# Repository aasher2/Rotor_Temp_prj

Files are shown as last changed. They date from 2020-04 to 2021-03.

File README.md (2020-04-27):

# Welcome!

We created this repository in case another team is tasked to bring this project to completion. All necessary documents and many useful links are provided.

To download this entire project as a zipped folder, simply click the "Clone or Download" drop-down to the right of the home page. The option to download as a zipped folder will then be presented. 

This repository is split between paths for firmware and hardware. The firmware path just leads to the final code used for the BLE server and BLE client. The hardware path diverges into paths for the final design and for the proof of concept design. Most of the documents/datasheets/references will be found in the proof of concept folder.

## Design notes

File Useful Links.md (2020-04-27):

# Useful Links

## Final Design Digi-key Cart
https://www.digikey.com/short/zz4mqt

## TinyPICO Information
TinyPICO GitHub repository: https://github.com/TinyPICO

## Amazon Links
TinyPICO Development Board: https://www.amazon.com/Unexpected-Maker-TinyPICO/dp/B07ZZKZDGQ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

ESP-WROOM-32 Development Board:
https://www.amazon.com/HiLetgo-ESP-WROOM-32-Development-Microcontroller-Integrated/dp/B0718T232Z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

Adafruit AD8495 Breakout Board:
https://www.amazon.com/Adafruit-Analog-Output-Thermocouple-Amplifier/dp/B00XW2N6E0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

## Calibrating the AD8495
https://www.instructables.com/id/AD8495-Breakout-Board-Solution/

## Setting up ESP32 with Energia/Arduino IDE (same process)
https://randomnerdtutorials.com/installing-the-esp32-board-in-arduino-ide-windows-instructions/

## Setting up BLE with ESP32
https://randomnerdtutorials.com/esp32-bluetooth-low-energy-ble-arduino-ide/

https://www.instructables.com/id/How-to-Use-BluetoothBLE-With-ESP32/

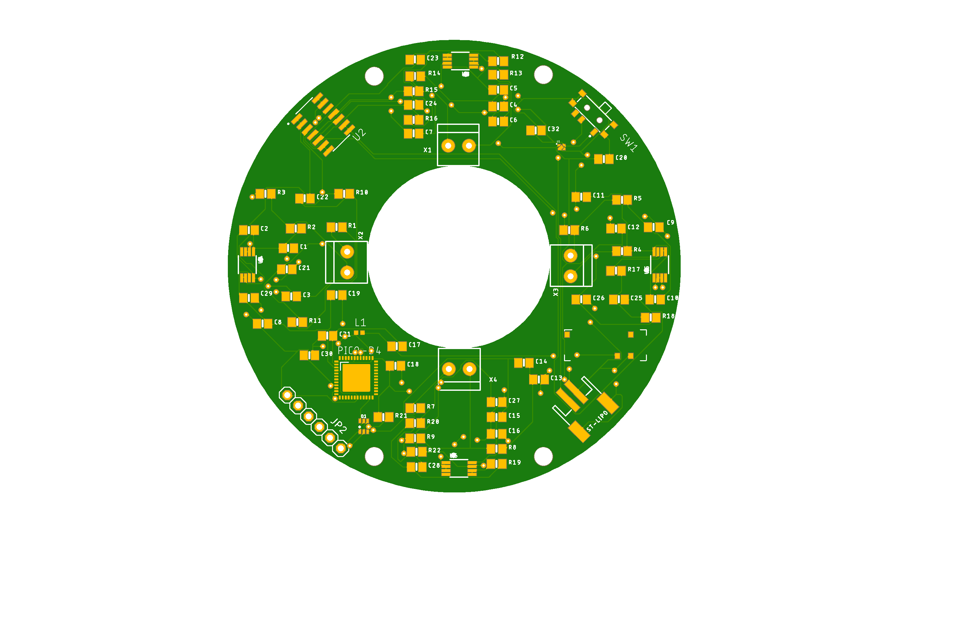
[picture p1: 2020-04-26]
Hardware/Final_Design/Layout.png

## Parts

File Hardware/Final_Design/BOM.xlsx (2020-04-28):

Manufacturer Part Number | Manufacturer | Digi-Key Part Number | Packaging | Quantity | Unit Price | Extended Price | Description | Hyperlink
ESP32-PICO-D4 | Espressif Systems | 1904-1029-1-ND | Cut Tape (CT) | 1 | 4.5 | $4.50 | RX TXRX MOD WIFI SURFACE MOUNT | Link (https://www.digikey.com/product-detail/en/ESP32-PICO-D4/1904-1029-1-ND/9381738/?itemSeq=324698362)
AD8497ARMZ-R7 | Analog Devices Inc. | AD8497ARMZ-R7CT-ND | Cut Tape (CT) | 4 | 6.14 | $24.56 | IC THERMOCOUPLE A W/COMP 8MSOP | Link (https://www.digikey.com/product-detail/en/AD8497ARMZ-R7/AD8497ARMZ-R7CT-ND/4909088/?itemSeq=324698358)
LM324AMX/NOPB | Texas Instruments | LM324AMX/NOPBCT-ND | Cut Tape (CT) | 1 | 1.02 | $1.02 | IC OPAMP GP 4 CIRCUIT 14SOIC | Link (https://www.digikey.com/product-detail/en/LM324AMX%2fNOPB/LM324AMX%2fNOPBCT-ND/1010531/?itemSeq=324698361)
C2012X7T2E104K125AE | TDK Corporation | 445-8883-1-ND | Cut Tape (CT) | 15 | 0.239 | $3.58 | CAP CER 0.1UF 250V X7T 0805 | Link (https://www.digikey.com/product-detail/en/C2012X7T2E104K125AE/445-8883-1-ND/3283672/?itemSeq=324698355)
C0805C103K1RACTU | KEMET | 399-1159-1-ND | Cut Tape (CT) | 5 | 0.1 | $0.50 | CAP CER 10000PF 100V X7R 0805 | Link (https://www.digikey.com/product-detail/en/C0805C103K1RACTU/399-1159-1-ND/411434/?itemSeq=324698359)
RL1220S-101-F | Susumu | 408-1403-1-ND | Cut Tape (CT) | 10 | 0.318 | $3.18 | RES SMD 100 OHM 1% 1/3W 0805 | Link (https://www.digikey.com/product-detail/en/RL1220S-101-F/408-1403-1-ND/2734781/?itemSeq=324698349)
MCU08050D1004BP100 | Vishay Beyschlag | 749-1876-1-ND | Cut Tape (CT) | 5 | 0.58 | $2.90 | RES SMD 1M OHM 0.1% 1/8W 0805 | Link (https://www.digikey.com/product-detail/en/MCU08050D1004BP100/749-1876-1-ND/8555710/?itemSeq=324698341)
ED555/2DS | On Shore Technology Inc. | ED1514-ND | Box | 4 | 1.06 | $4.24 | TERM BLK 2POS SIDE ENT 3.5MM PCB | Link (https://www.digikey.com/product-detail/en/ED555%2f2DS/ED1514-ND/182983/?itemSeq=324698333)
C0805C106J8RACAUTO | KEMET | 399-15693-1-ND | Cut Tape (CT) | 1 | 0.83 | $0.83 | CAP CER 10UF 10V X7R 0805 | Link (https://www.digikey.com/product-detail/en/C0805C106J8RACAUTO/399-15693-1-ND/7427573/?itemSeq=324698344)
CC0805BRNPO9BNR75 | Yageo | 311-4135-1-ND | Cut Tape (CT) | 1 | 0.3 | $0.30 | CAP CER 0.75PF 50V NPO 0805 | Link (https://www.digikey.com/product-detail/en/CC0805BRNPO9BNR75/311-4135-1-ND/8025224/?itemSeq=324698337)
CC0805BRNPO9BN1R5 | Yageo | 311-4126-1-ND | Cut Tape (CT) | 1 | 0.19 | $0.19 | CAP CER 1.5PF 50V NPO 0805 | Link (https://www.digikey.com/product-detail/en/CC0805BRNPO9BN1R5/311-4126-1-ND/8025215/?itemSeq=324698346)
C0805C105K4RACTU | KEMET | 399-1284-1-ND | Cut Tape (CT) | 2 | 0.15 | $0.30 | CAP CER 1UF 16V X7R 0805 | Link (https://www.digikey.com/product-detail/en/C0805C105K4RACTU/399-1284-1-ND/416060/?itemSeq=324698338)
0805CS-7N5EKTS | Delta Electronics/Components | 2035-1315-1-ND | Cut Tape (CT) | 2 | 0.25 | $0.50 | CHIP INDUCTOR 7.5NH10% 600MA 0.1 | Link (https://www.digikey.com/product-detail/en/0805CS-7N5EKTS/2035-1315-1-ND/10129548/?itemSeq=324698352)
NCP170AMX300TCG | ON Semiconductor | NCP170AMX300TCGOSCT-ND | Cut Tape (CT) | 1 | 0.47 | $0.47 | IC REG LINEAR 3V 150MA 4XDFN | Link (https://www.digikey.com/product-detail/en/NCP170AMX300TCG/NCP170AMX300TCGOSCT-ND/5131385/?itemSeq=324698343)
1578 | Adafruit Industries LLC | 1528-1841-ND | Bulk | 1 | 7.95 | $7.95 | BATTERY LITHIUM 3.7V 500MAH | Link (https://www.digikey.com/product-detail/en/1578/1528-1841-ND/5054539/?itemSeq=324698327)
PRO-OB-440 | Proant AB | 1532-1001-1-ND | Cut Tape (CT) | 1 | 0.74 | $0.74 | RF ANT 2.4GHZ STAMPED MET SLD | Link (https://www.digikey.com/product-detail/en/PRO-OB-440/1532-1001-1-ND/4895684/?itemSeq=324698329)
RC0805FR-0710KL | Yageo | 311-10.0KCRCT-ND | Cut Tape (CT) | 5 | 0.1 | $0.50 | RES SMD 10K OHM 1% 1/8W 0805 | Link (https://www.digikey.com/product-detail/en/RC0805FR-0710KL/311-10.0KCRCT-ND/730482/?itemSeq=324698381)
S2B-PH-SM4-TB(LF)(SN) | JST Sales America Inc. | 455-1749-1-ND | Cut Tape (CT) | 1 | 0.58 | $0.58 | CONN HEADER SMD R/A 2POS 2MM | Link (https://www.digikey.com/product-detail/en/S2B-PH-SM4-TB(LF)(SN)/455-1749-1-ND/926846/?itemSeq=324698326)
HVC0805T2504JET | Ohmite | HVC0805T2504JETCT-ND | Cut Tape (CT) | 5 | 1.88 | $9.40 | RES SMD 2.5M OHM 5% 1/8W 0805 | Link (https://www.digikey.com/product-detail/en/HVC0805T2504JET/HVC0805T2504JETCT-ND/4809224/?itemSeq=324698328)
CRG0805F150K | TE Connectivity Passive Product | A126340CT-ND | Cut Tape (CT) | 5 | 0.1 | $0.50 | RES SMD 150K OHM 1% 1/8W 0805 | Link (https://www.digikey.com/product-detail/en/CRG0805F150K/A126340CT-ND/7603395/?itemSeq=324698383)
C0805C103K1RAC7210 | KEMET | 399-17617-2-ND | Tape & Reel (TR) | 8 | 0.1 | $0.80 | CAP CER SMD 0805 .01UF 100V X7R | Link (https://www.digikey.com/product-detail/en/C0805C103K1RAC7210/399-17617-1-ND/8572617/?itemSeq=324698382)
RC0805FR-0710KL | Yageo | 311-10.0KCRTR-ND | Tape & Reel (TR) | 2 | 0.1 | $0.20 | RES SMD 10K OHM 1% 1/8W 0805 | Link (https://www.digikey.com/product-detail/en/RC0805FR-0710KL/311-10.0KCRCT-ND/730482/?itemSeq=324698381)
MLL1200S | TE Connectivity ALCOSWITCH Switches | 450-1577-ND | Bulk | 1 | 2.54 | $2.54 | SWITCH SLIDE SPDT 300MA 4V | Link (https://www.digikey.com/product-detail/en/MLL1200S/450-1577-ND/1201378/?itemSeq=324698308)
MBT3904DW1T1G | ON Semiconductor | MBT3904DW1T1GOSTR-ND | Tape & Reel (TR) | 1 | 0.19 | $0.19 | TRANS 2NPN 40V 0.2A SC88 | Link (https://www.digikey.com/product-detail/en/MBT3904DW1T1G/MBT3904DW1T1GOSCT-ND/918012/?itemSeq=324698321)
D01-9923246 | Harwin Inc. | 952-2521-ND | Bulk | 1 | 5.23 | $5.23 | CONN SIL HDR MALE PIN 32POS TIN | Link (https://www.digikey.com/product-detail/en/D01-9923246/952-2521-ND/3918909/?itemSeq=324698310)
3309 | Adafruit Industries LLC | 1528-1800-ND | Bulk | 1 | 5.95 | $5.95 | CP2104 FRIEND USB TO SERIAL BRD | Link (https://www.digikey.com/product-detail/en/3309/1528-1800-ND/6560940/?itemSeq=324698306)
1904 | Adafruit Industries LLC | N/A |  | 1 | 6.95 | $6.95 | Adafruit Micro-Lipo Charger for LiPo/LiIon Batt w/MicroUSB Jack | Link (https://www.adafruit.com/product/1904)

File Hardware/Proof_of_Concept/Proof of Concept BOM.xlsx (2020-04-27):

Test Circuit Component Breakdown
# | Description | Manufacturer/Seller | Vendor | Quanity | Price per Unit | Extended Price
1 | PCB Prototype Board | AiTrip | Amazon | 1 | $10.29 | $10.29
2 | TinyPico Development Board | Unexpected Maker | Amazon | 1 | $29.95 | $29.95
3 | LiPo Battery Charger | Adafruit Industries LLC | Amazon | 1 | $8.30 | $8.30
4 | ESP-WROOM-32 Development Board | HiLetgo | Amazon | 1 | $10.99 | $10.99
5 | 1200 mAh LiPo Battery | Adafruit Industries LLC | Adafruit Industries LLC | 1 | $9.95 | $9.95
6 | AD8495 Breakout Board | Adafruit Industries LLC | Amazon | 1 | $16.98 | $16.98
7 | K-Type Thermocouple | Digilent, Inc. | Digi-Key | 2 | $9.99 | $19.98
8 | Ceramic Chip Capacitors | Hilitchi | Amazon | 1 | $14.85 | $14.85
9 | 1/4W Axial Resistor Kit | Joe Knows Electronics | Amazon | 1 | $14.99 | $14.99
10 | IC Socket Holders | Glarks | Amazon | 1 | $8.90 | $8.90
11 | LM358 | MCIGICM | Amazon | 1 | $6.99 | $6.99
 |  |  |  | Totals | $142.18 | $152.17

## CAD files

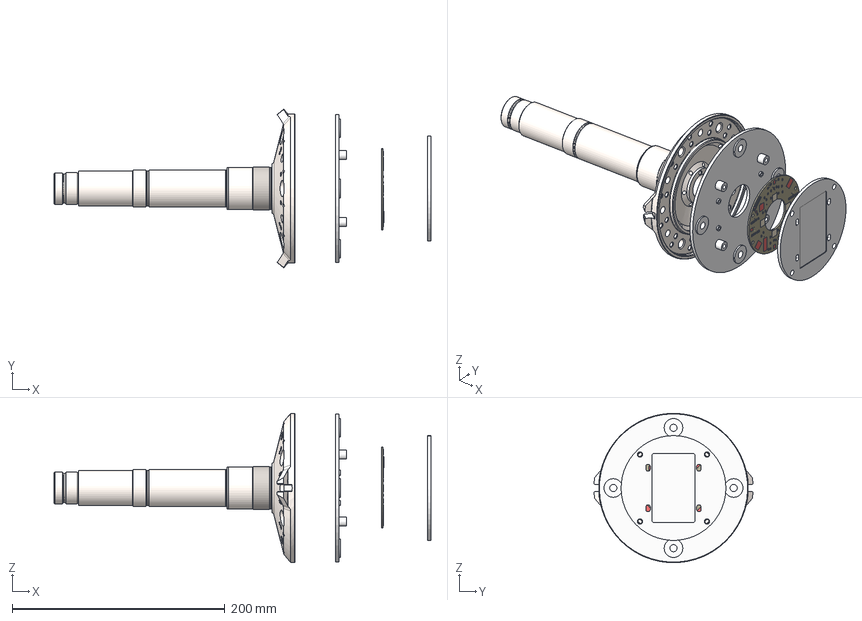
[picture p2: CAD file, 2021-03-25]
Hardware/Final_Design/Mounting Solution CAD Files/AluminumBoardMount.stp
354.0 x 149.2 x 140.2 mm
31480-1004_Interference_fits
Board
0.01uF x 32
LIPO
7.5nH
ESP32-PICO-D4
MUN5214DW1T1G
1M x 22
MLL1200S
PRO-OB-440
NCP170AMX300TCG
LM324
AD8495ARMZ x 4
3.5mm terminal x 4
1X06
AluminumMountingPlate
BatteryMount

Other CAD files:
Hardware/Final_Design/Mounting Solution CAD Files/AluminumBoardMount.f3d

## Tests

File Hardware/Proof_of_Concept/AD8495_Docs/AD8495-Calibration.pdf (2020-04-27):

instructables

## AD8495 Breakout Board Solution

by liverdye

Hey there! I purchased a bunch of AD8495 breakout boards to record (5) type-K thermocouples. These were the perfect match for my range of temp and application - or so I thought...My readings were fluctuating and inaccurate (51% error!).
After running some calibration tests, lots of swearing, crying, and acceptance of my doom (i kid!)- I found a solution to get precise and accurate readings from the AD8495 breakout board (ADBB). My colleagues and I worked on this together, so they deserve some credit too!
Now if you are having similar issues with your board, try this out. To keep things straightforward, I abbreviated my components. Below is a "glossary" of those abbreviations.
Glossary:
TC - Omega type-k thermocouple connected to ADBB.
FTC - Fluke 179 type-k thermocouple.
CTC - controlled, reliable type-k thermocouple device ADBB - ad8495 breakout board

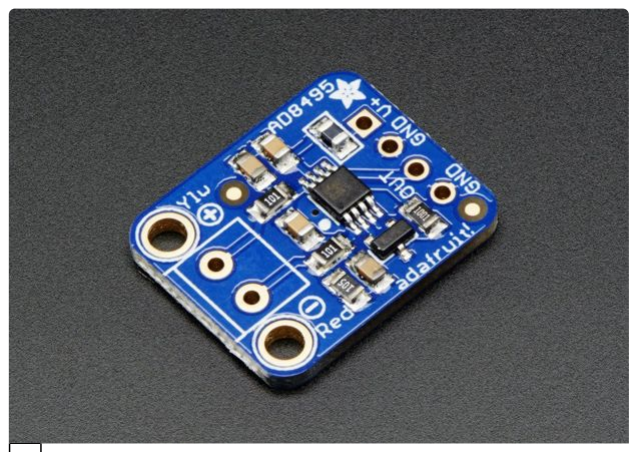
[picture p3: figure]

1.
Taken
from
Adafruit
website,
this
is
not my

photo.

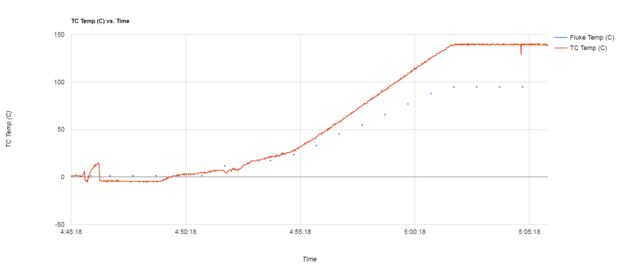
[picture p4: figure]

AD8495 Breakout Board Solution: Page 1

### Step 1: Precision

My readings were fluctuating up to +/- 10 degrees. In order to make the ADBB precise, a simple low pass filter will make a world of difference.
Do this by placing a .1uF capacitor and a 1M Ohm resistor in your circuit (see photo). If you have a 1uF capacitor, that will work too.
That is it for precision. The addition of the RC low pass filter should clean up your signal A LOT.

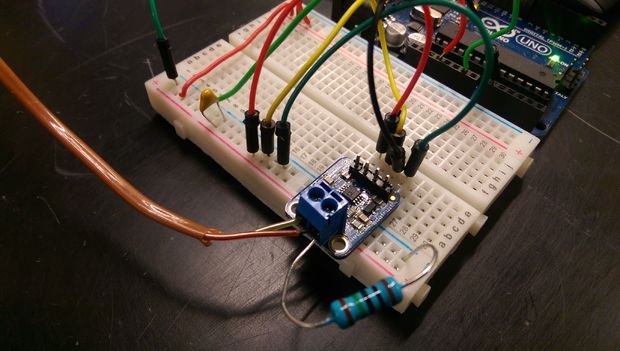
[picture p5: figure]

### Step 2: Accuracy

Objective:
In this next part, you will be conducting some tests using the equipment listed below. The purpose is to measure a "wide" temperature range using a reliable thermocouple (CTC) and the ADBB. Data from both thermocouples will be used to calculate a slope intercept equation. I will include all the calculation steps!
Equipment:
-At least (1) reliable type-k thermocouple measurement device. (I'm using Fluke 179 with type-K TC).
-Type k TC with ADBB
-Hot plate to boil water
-Glass container for boiling water
-Crushed ice
-DAQ equipment (Arduino & Python software in this example)
Procedure:
1. Initialize your DAQ system. For me, I use the Serial Comm. to send data from Arduino to Python, which compiles the data in a excel file w/ headers. Mark your start time.
2. Start with an ice bath (90% crushed ice, 10% water) on a cooled hot plate
3. Place both thermocouples in the container and turn on hot plate to around 150 deg C.
4. Make sure both thermocouples (TC & CTC) are in the center of the container - not touching the sides or bottom!! (see pictures)
5. Every 30-60 seconds (I prefer 30 sec for more samples), write down the temperature of the CTC. In this example, I'm reading it from my Fluke's LCD.
6. Repeat until water is boiling (about 17 minutes) and the CTC reaches steady state of 95-100 deg C (depending on your altitude). The ADBB should be at steady state as well, it just won't be accurate.
Calculations:
Your main variables will be temperature and voltage, in fact your temperature is a function of voltage, T(V). If you want to test for linearity, plot your ADBB temp vs voltage (see photos).
"Y = Control max" : this should be 95-100 deg C, read from your CTC.
"Y1= Control min" : this should be 0 deg C (the temp of an ice bath, but verify with your CTC).
"X = ADBB max " : this should be voltage read from Arduino once boiling point and steady state is reached (about 1.71 for me).
"X1= ADBB min" : voltage when TC is in ice bath, mine came out to be 1.23 V.
With those values, see the photo for the calculations and the solution to this problem!!!

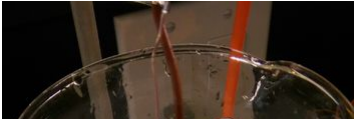
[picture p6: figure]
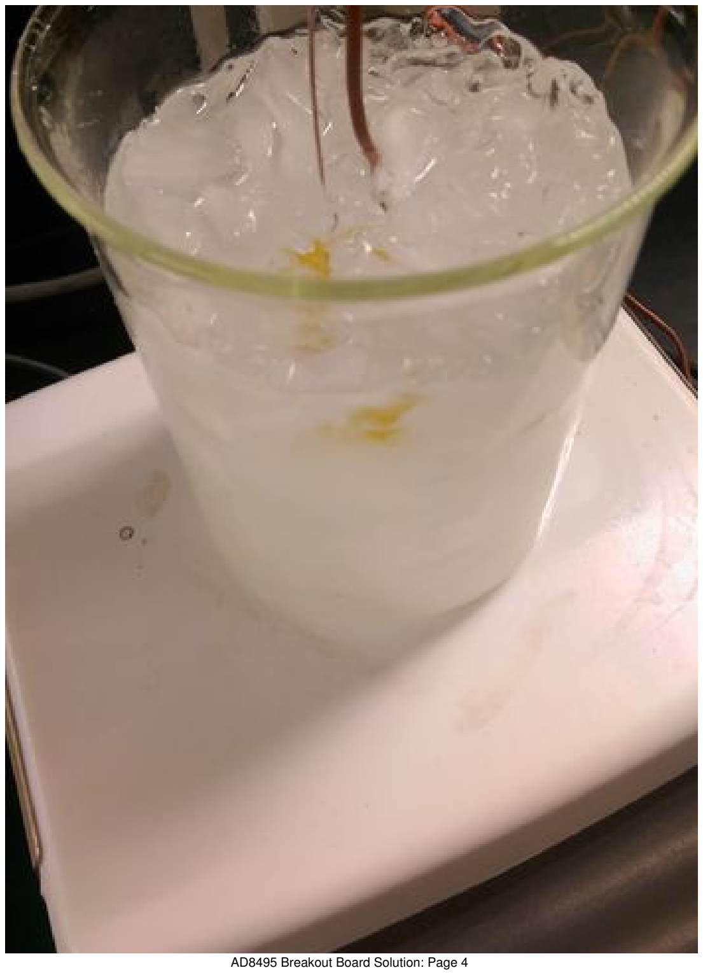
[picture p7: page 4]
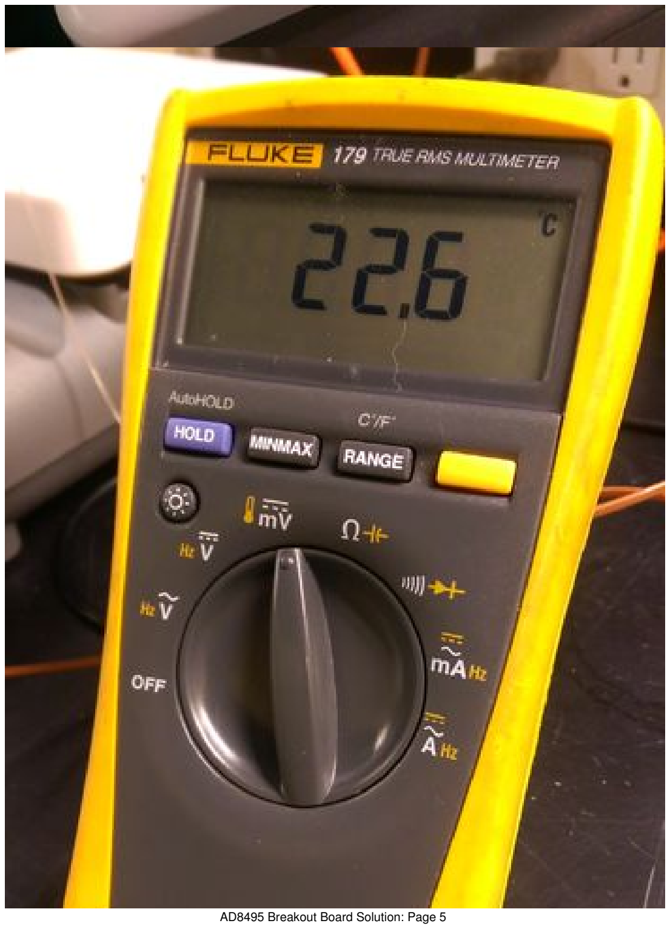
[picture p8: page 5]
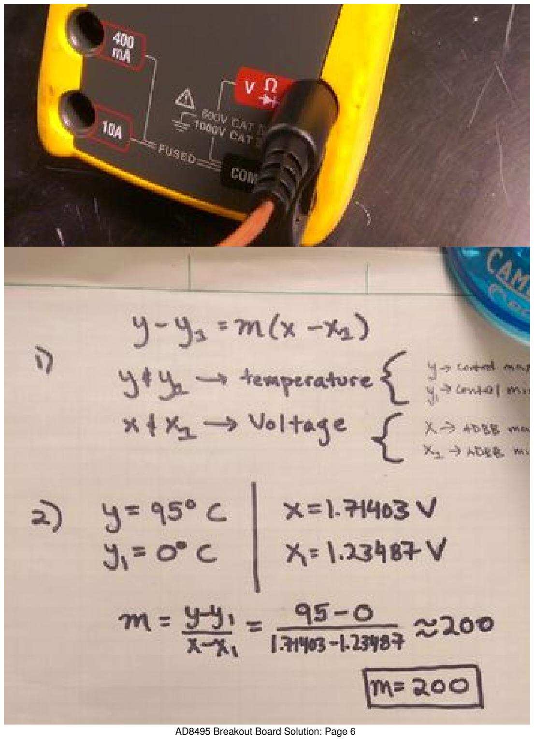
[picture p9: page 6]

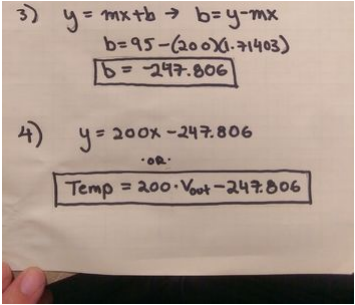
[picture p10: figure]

### Step 3: Software

With the new equation, you will need to edit your Arduino code (or whatever you're using). I've included screen shots of before and after. Also, I've included my new tests results with the new equation.

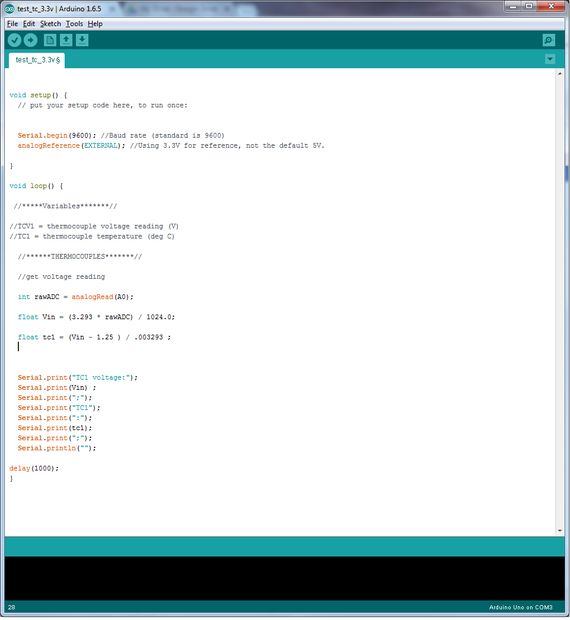
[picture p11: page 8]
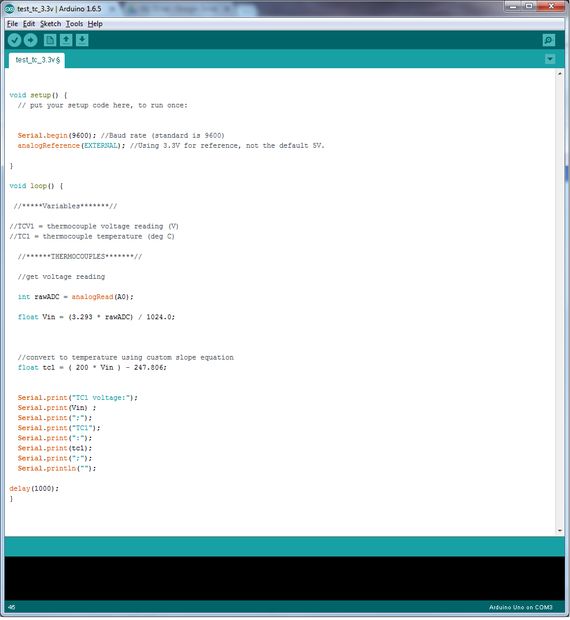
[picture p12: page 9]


### Step 4: Conclusion

I tested the equation by plugging in 1.71 V and my output was 94.2 deg C. That is .86% error from 95 deg C! Much improvement from 51% error that I was receiving before.
Comparing your ADBB data to reliable data from a controlled TC will help you find the new equation that will give you accurate readings (read: scrap the equation that is printed on the back of the AD8495 breakout board).
Applying an RC low pass filter will give you precise readings.
Combining both methods will solve your issues with the AD8495 breakout board that I encountered.

Follow the process I outlined and replace the equation on the back of AD8495 with the equation you develop from the process. If you don't have a hot plate, a pot of water on your stovetop will work too.
Thank you for your time, I hope this helps you with your projects. Please feel free to ask questions and I will do my best to answer. Happy tinkering!

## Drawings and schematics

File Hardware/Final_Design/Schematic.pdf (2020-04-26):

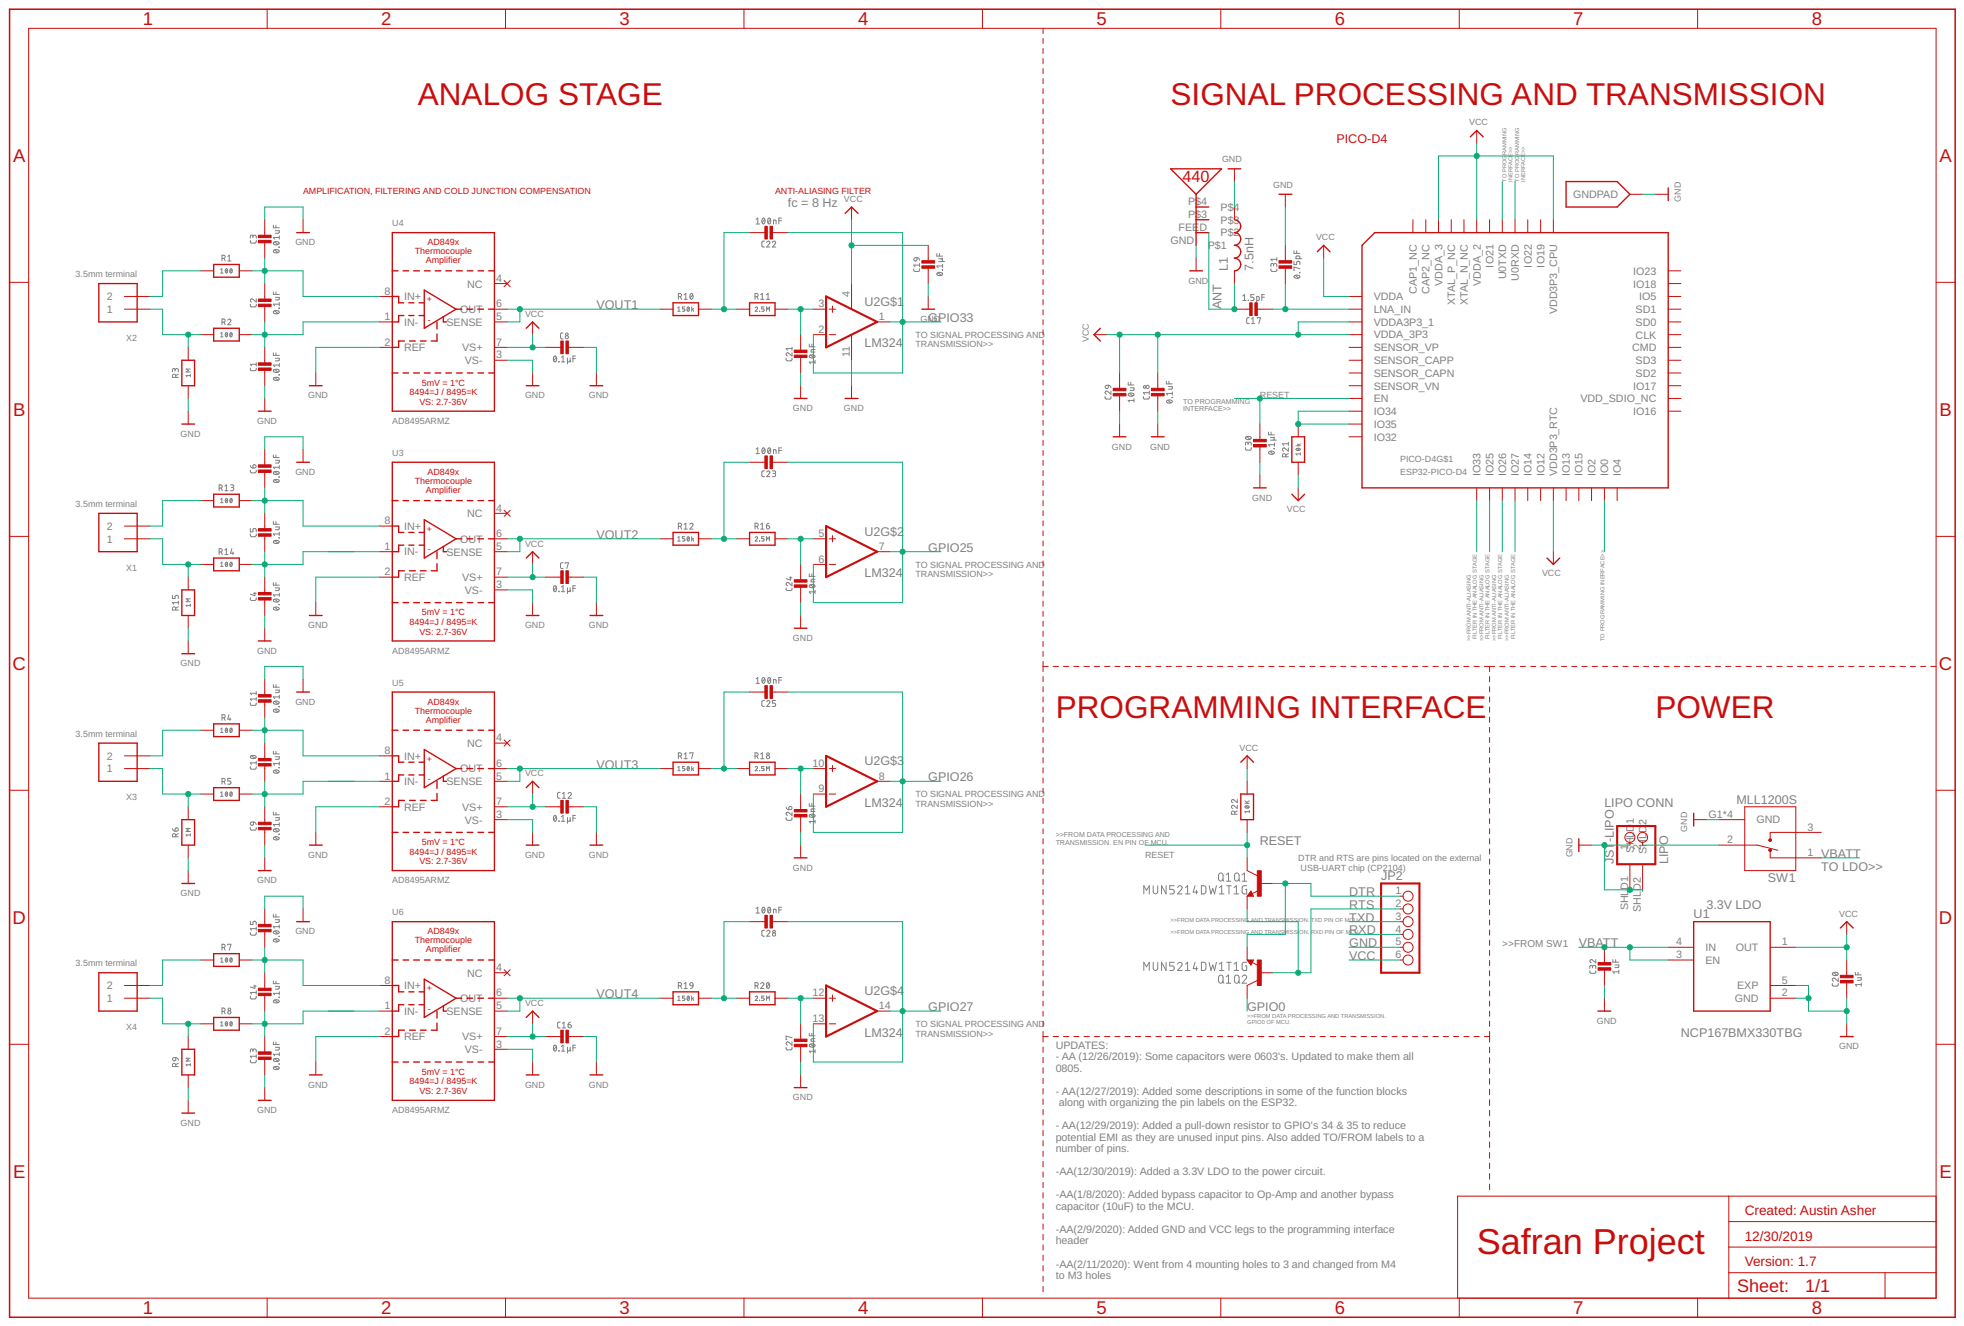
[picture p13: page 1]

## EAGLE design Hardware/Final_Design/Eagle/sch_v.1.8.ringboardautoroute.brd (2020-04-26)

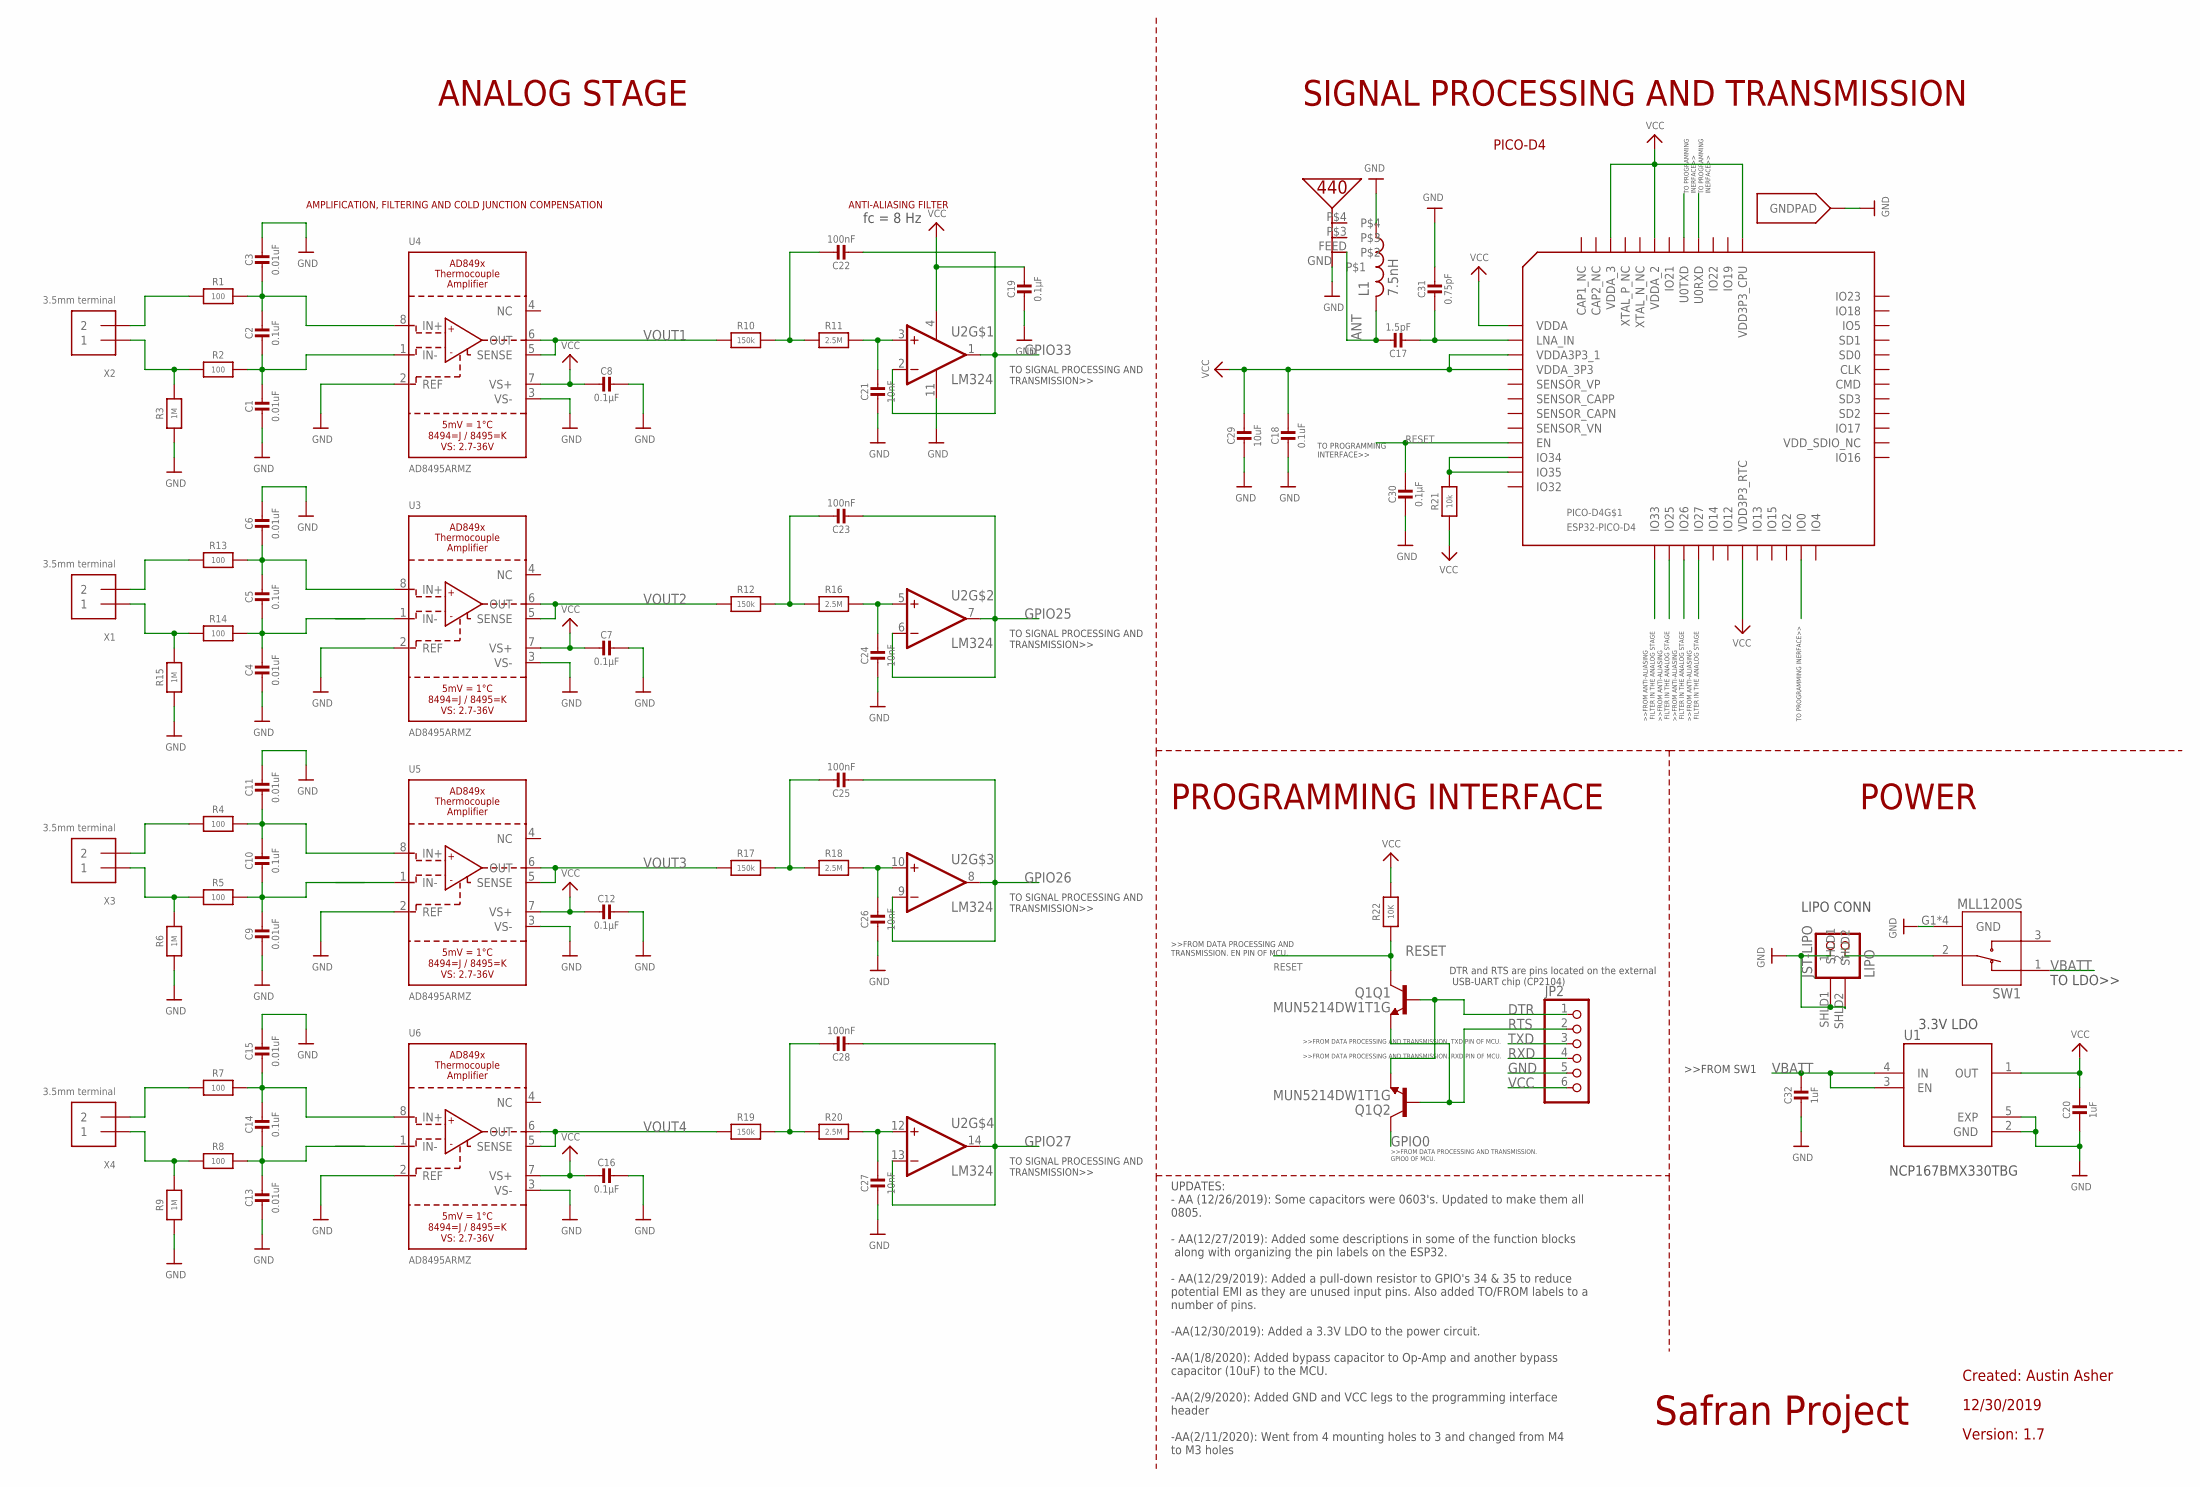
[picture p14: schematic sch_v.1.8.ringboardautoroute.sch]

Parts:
C1, C3, C4, C6, C9, C11, C13, C15: 0.01uF; 0805-NO@1
C2, C5, C10, C14, C18: 0.1uF; 0805-NO@1
C7, C8, C12, C16, C19, C30: 0.1µF; 0805-NO@1
C17: 1.5pF; 0805-NO@1
C20, C32: 1uF; 0805-NO@1
C21, C24, C26, C27: 10nF; 0805-NO@1
C22, C23, C25, C28: 100nF; 0805-NO@1
C29: 10uF; 0805-NO@1
C31: 0.75pF; 0805-NO@1
JP2: PINHD-1X6; 1X06
JST-LIPO: LIPO; JSTPH2
L1: 7.5nH; RESC0402_N
PICO-D4: ESP32-PICO-D4; PICO-D4-QFN48
Q1: MUN5214DW1T1G; DUAL_NPN_SC70-6
R1, R2, R4, R5, R7, R8, R13, R14: 100; 0805-NO
R3, R6, R9, R15: 1M; 0805-NO
R10, R12, R17, R19: 150k; 0805-NO
R11, R16, R18, R20: 2.5M; 0805-NO
R21: 10k; 0805-NO
R22: 10K; 0805-NO
SW1: MLL1200S; SW_MLL1200S
U1: NCP170AMX300TCG; VREG_NCP170AMX300TCG
U2: LM324; SOIC127P600X175-14N
U3, U4, U5, U6: AD8495ARMZ; MSOP8_0.65MM
U$35: PRO-OB-440
X1, X2, X3, X4: 3.5mm terminal; TERMBLOCK_1X2-3.5MM

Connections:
ANT: C17.1, L1.2, U$35.FEED
DTR: JP2.1, Q1.1 (E), Q1.5 (B)
GND: C1.2, C3.1, C4.2, C6.1, C7.1, C8.1, C9.2, C11.1, C12.1, C13.2, C15.1, C16.1, C18.2, C19.2, C20.2, C21.2, C24.2, C26.2, C27.2, C29.2, C30.2, C31.1, C32.2, JP2.5, JST-LIPO.1, JST-LIPO.SHLD1, JST-LIPO.SHLD2, L1.1, PICO-D4.EXP (GNDPAD), R3.1, R6.1, R9.1, R15.1, SW1.G1 (GND), SW1.G2 (GND), SW1.G3 (GND), SW1.G4 (GND), U1.2 (GND), U1.5 (EXP), U2.11 (VCC-), U3.2 (REF), U3.3 (VS-), U4.2 (REF), U4.3 (VS-), U5.2 (REF), U5.3 (VS-), U6.2 (REF), U6.3 (VS-), U$35.GND
GPIO0: PICO-D4.23 (IO0), Q1.6 (C)
GPIO25: C23.2, U2.6 (INVERTING_INPUT2), U2.7 (OUTPUT2)
GPIO26: C25.2, U2.8 (OUTPUT3), U2.9 (INVERTING_INPUT3)
GPIO27: C28.2, U2.13 (INVERTING_INPUT4), U2.14 (OUTPUT4)
GPIO33: C22.2, U2.1 (OUTPUT1), U2.2 (INVERTING_INPUT1)
IN+: R13.1, X1.2
IN+1: R1.1, X2.2
IN+2: R4.1, X3.2
IN+3: R7.1, X4.2
IN-: R14.1, R15.2, X1.1
IN-1: R2.1, R3.2, X2.1
IN-2: R5.1, R6.2, X3.1
IN-3: R8.1, R9.2, X4.1
IO12: PICO-D4.18 (IO12)
IO21: PICO-D4.42 (IO21)
LNA_IN: C17.2, C31.2, PICO-D4.2 (LNA_IN)
unnamed: C2.1, C3.2, R1.2, U4.8 (IN+)
unnamed: C5.1, C6.2, R13.2, U3.8 (IN+)
unnamed: C4.1, C5.2, R14.2
unnamed: C1.1, C2.2, R2.2, U4.1 (IN-)
unnamed: C10.1, C11.2, R4.2, U5.8 (IN+)
unnamed: C9.1, C10.2, R5.2
unnamed: C14.1, C15.2, R7.2, U6.8 (IN+)
unnamed: C13.1, C14.2, R8.2
unnamed: JST-LIPO.2, SW1.2
unnamed: C22.1, R10.2, R11.1
unnamed: C21.1, R11.2, U2.3 (NON-INVERTING_INPUT1)
unnamed: C24.1, R16.2, U2.5 (NON-INVERTING_INPUT2)
unnamed: C23.1, R12.2, R16.1
unnamed: C25.1, R17.2, R18.1
unnamed: C28.1, R19.2, R20.1
unnamed: C26.1, R18.2, U2.10 (NON-INVERTING_INPUT3)
unnamed: C27.1, R20.2, U2.12 (NON-INVERTING_INPUT4)
unnamed: PICO-D4.10 (IO34), PICO-D4.11 (IO35), R21.2
RESET: C30.1, PICO-D4.9 (EN), Q1.3 (C), R22.1
RTS: JP2.2, Q1.2 (B), Q1.4 (E)
RXD: JP2.4, PICO-D4.40 (U0RXD)
SENSOR_CAPN: PICO-D4.7 (SENSOR_CAPN)
TXD: JP2.3, PICO-D4.41 (U0TXD)
VBATT: C32.1, SW1.1, U1.3 (EN), U1.4 (IN)
VCC: C7.2, C8.2, C12.2, C16.2, C18.1, C19.1, C20.1, C29.1, JP2.6, PICO-D4.1 (VDDA), PICO-D4.3 (VDDA3P3_1), PICO-D4.4 (VDDA_3P3), PICO-D4.19 (VDD3P3_RTC), PICO-D4.37 (VDD3P3_CPU), PICO-D4.43 (VDDA_2), PICO-D4.46 (VDDA_3), R21.1, R22.2, U1.1 (OUT), U2.4 (VCC+), U3.7 (VS+), U4.7 (VS+), U5.7 (VS+), U6.7 (VS+)
VOUT1: R10.1, U4.5 (SENSE), U4.6 (OUT)
VOUT2: R12.1, U3.5 (SENSE), U3.6 (OUT)
VOUT3: R17.1, U5.5 (SENSE), U5.6 (OUT)
VOUT4: R19.1, U6.5 (SENSE), U6.6 (OUT)

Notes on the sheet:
LIPO CONN
Created: Austin Asher
Safran Project
12/30/2019
Version: 1.7
PICO-D4
ANALOG STAGE
PROGRAMMING INTERFACE
POWER
SIGNAL PROCESSING AND TRANSMISSION
UPDATES: - AA (12/26/2019): Some capacitors were 0603's. Updated to make them all 0805. - AA(12/27/2019): Added some descriptions in some of the function blocks along with organizing the pin labels on the ESP32. - AA(12/29/2019): Added a pull-down resistor to GPIO's 34 & 35 to reduce potential EMI 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
DTR and RTS are pins located on the external USB-UART chip (CP2104)
AMPLIFICATION, FILTERING AND COLD JUNCTION COMPENSATION
ANTI-ALIASING FILTER
TO SIGNAL PROCESSING AND TRANSMISSION>>
TO PROGRAMMING INERFACE>>
TO PROGRAMMING INTERFACE>>
TO PROGRAMMING INERFACE>>
NCP167BMX330TBG
TO LDO>>
3.3V LDO
fc = 8 Hz

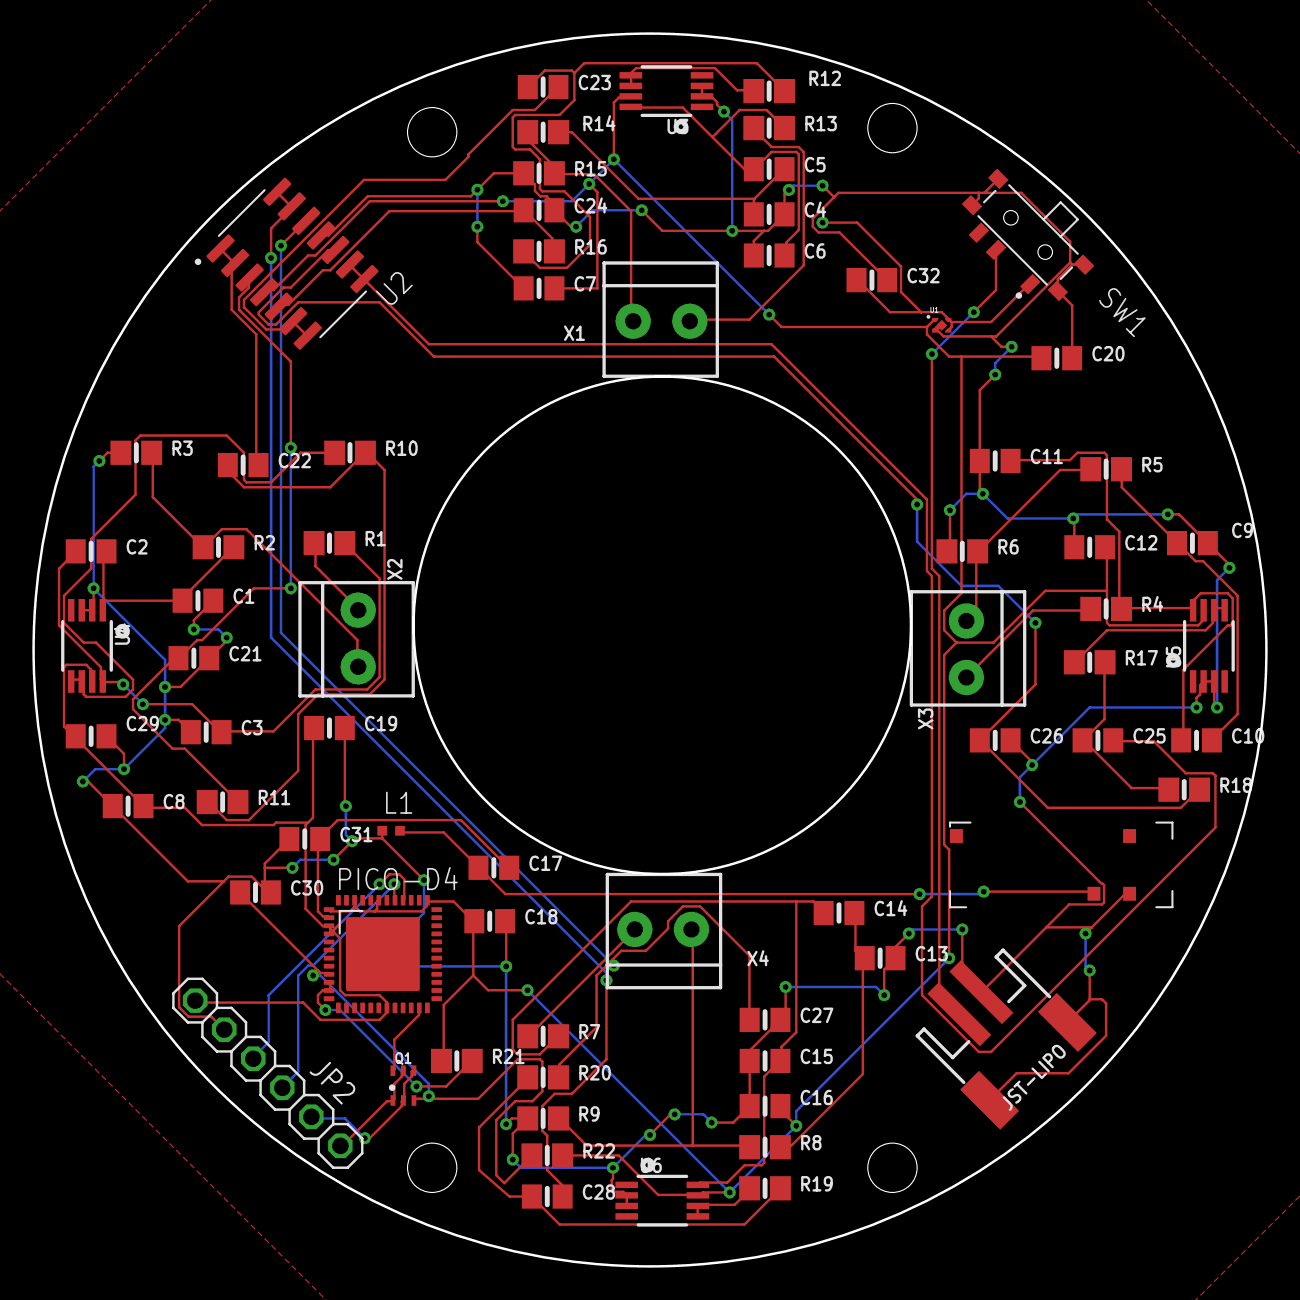
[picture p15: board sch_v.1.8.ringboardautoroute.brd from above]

Board: 2 copper layers, 76.2 x 76.2 mm, 71 parts (0 on the bottom side), 45 nets.

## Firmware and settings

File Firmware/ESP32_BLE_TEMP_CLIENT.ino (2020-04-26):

#include "BLEDevice.h"


static BLEUUID serviceUUID((uint16_t)0x181A);//service UUID from the server
static BLEUUID charUUID((uint16_t)0x2A6E);//characteritic UUID from server

static boolean doConnect = false;
static boolean connected = false;
static boolean doScan = false;
static BLERemoteCharacteristic* pRemoteCharacteristic;
static BLEAdvertisedDevice* myDevice;



static void notifyCallback(BLERemoteCharacteristic* pBLERemoteCharacteristic,uint8_t* pData,size_t length, bool isNotify) 
{    
    Serial.println((char*)pData);
}

class MyClientCallback : public BLEClientCallbacks 
{
  void onConnect(BLEClient* pclient) 
  {
  }

  void onDisconnect(BLEClient* pclient) 
  {
    connected = false;
    Serial.println("onDisconnect");
  }
};

bool connectToServer() 
{
    BLEClient*  pClient  = BLEDevice::createClient();
    pClient->setClientCallbacks(new MyClientCallback());

    // Connect to the BLE Server.
    pClient->connect(myDevice);  // if you pass BLEAdvertisedDevice instead of address, it will be recognized type of peer device address (public or private)

    // Obtain a reference to the service we are after in the remote BLE server.
    BLERemoteService* pRemoteService = pClient->getService(serviceUUID);
    if (pRemoteService == nullptr)
    {   
      pClient->disconnect();
      return false;
    }

    // Obtain a reference to the characteristic in the service of the remote BLE server.
    pRemoteCharacteristic = pRemoteService->getCharacteristic(charUUID);
    if (pRemoteCharacteristic == nullptr) 
    {
      pClient->disconnect();
      return false;
    }

    // Read the value of the characteristic.
    if(pRemoteCharacteristic->canRead()) 
    {
      std::string value = pRemoteCharacteristic->readValue();
    }

    if(pRemoteCharacteristic->canNotify())
      pRemoteCharacteristic->registerForNotify(notifyCallback);

    connected = true;
    return true;
}
/**
 * Scan for BLE servers and find the first one that advertises the service we are looking for.
 */
class MyAdvertisedDeviceCallbacks: public BLEAdvertisedDeviceCallbacks 
{
   // Called for each advertising BLE server.
  void onResult(BLEAdvertisedDevice advertisedDevice) 
  {
    // We have found a device, let us now see if it contains the service we are looking for.
    if (advertisedDevice.haveServiceUUID() && advertisedDevice.isAdvertisingService(serviceUUID)) 
    {
      BLEDevice::getScan()->stop();//we have found the correct server. stop scanning.
      myDevice = new BLEAdvertisedDevice(advertisedDevice);
      doConnect = true;
      doScan = true;
    }
  } 
}; 

void setup() 
{
  Serial.begin(115200, SERIAL_8N1);
  BLEDevice::init("");
  // Retrieve a Scanner and set the callback we want to use to be informed when we
  // have detected a new device.  Specify that we want active scanning and start the
  // scan to run for 5 seconds. CHECK BLEScan.h FOR INFO ON FUNCTION CALLS HERE
  BLEScan* pBLEScan = BLEDevice::getScan();
  pBLEScan->setAdvertisedDeviceCallbacks(new MyAdvertisedDeviceCallbacks());
  pBLEScan->setInterval(1349);//how long to wait between scans
  pBLEScan->setWindow(449);//how long to scan
  pBLEScan->setActiveScan(true);
  pBLEScan->start(5, false);
} // End of setup.

void loop()
{

  // If the flag "doConnect" is true then we have scanned for and found the desired
  // BLE Server with which we wish to connect.  Now we connect to it.  Once we are 
  // connected we set the connected flag to be true.
  if (doConnect == true) 
  {
    if (connectToServer()) 
    {
      //Serial.println("We are now connected to the BLE Server.");
    } 
    else 
    {
      //Serial.println("We have failed to connect to the server; there is nothin more we will do.");
    }
    doConnect = false;
  }
  delay(1000); // Delay a second between loops.
} // End of loop

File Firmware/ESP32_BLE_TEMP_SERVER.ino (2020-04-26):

#include <BLEDevice.h>
#include <BLEServer.h>
#include <BLEUtils.h>
#include <BLE2902.h>
#include <driver/adc.h>
#include "esp32-hal-cpu.h"


//Temp measurement variables
float Temp; //Temperature
float Vout; //Voltage after adc
float SenVal; // Analog Sensor value
float Beta = 0.9;//RC factor
float FilteredVal;//voltage after digital filter


bool deviceConnected = false;

void getTemp();//adc & temp function declaration
void BLETransfer(int16_t);


#define enviornmentService BLEUUID((uint16_t)0x181A)//serviceUUID

 BLECharacteristic temperatureCharacteristic(BLEUUID((uint16_t)0x2A6E),//characteristic UUID
 BLECharacteristic::PROPERTY_READ |BLECharacteristic::PROPERTY_NOTIFY);

class MyServerCallbacks: public BLEServerCallbacks 
{
    void onConnect(BLEServer* pServer) 
    {
      deviceConnected = true;
    };

    void onDisconnect(BLEServer* pServer) 
    {
      deviceConnected = false;
    }
};

void setup() 
{ 
  setCpuFrequencyMhz(80); //Set CPU clock to 80MHz
  adc1_config_width(ADC_WIDTH_BIT_12);//12 bit resolution
  adc1_config_channel_atten(ADC1_CHANNEL_5, ADC_ATTEN_DB_11);
  
  // Create the BLE Device
  BLEDevice::init("MyESP32");
  esp_ble_tx_power_set(ESP_BLE_PWR_TYPE_ADV, ESP_PWR_LVL_N14);//set tx power for BLE

  // Create the BLE Server
  BLEServer *pServer = BLEDevice::createServer();
  pServer->setCallbacks(new MyServerCallbacks());

  // Create the BLE Service
  BLEService *pEnviornment = pServer->createService(enviornmentService);

  // Create a BLE Characteristic
  pEnviornment->addCharacteristic(&temperatureCharacteristic);

  // Create a BLE Descriptor
  temperatureCharacteristic.addDescriptor(new BLE2902());
  BLEDescriptor TemperatureDescriptor(BLEUUID((uint16_t)0x2901));
  TemperatureDescriptor.setValue("Thermocouple Temperature °C");
  temperatureCharacteristic.addDescriptor(&TemperatureDescriptor);

  pServer->getAdvertising()->addServiceUUID(enviornmentService);

  pEnviornment->start(); // Start the service

  pServer->getAdvertising()->start();// Start advertising  
}

void loop() 
{ 
  if (deviceConnected)//if there is a client connected/paired
  {
    getTemp();//call adc/temp conversion function
    char txtString[10]; //buffer used to store temp value as a string
    sprintf(txtString, "%2.3f", Temp);//convert the temp float to a string
    temperatureCharacteristic.setValue(txtString);//set the characteristic to the temp string
    temperatureCharacteristic.notify();//send value
  }
   delay(1000);//send value 1/s
}

void getTemp()
{
  SenVal = adc1_get_raw(ADC1_CHANNEL_5); //Analog value from AD8495 output pin
  Vout = (SenVal *3.434)/ 4095; //Conversion analog to digital for the temperature read voltage 
  FilteredVal = FilteredVal - (Beta*(FilteredVal-Vout));//digital filter
  Temp = (184.61*FilteredVal)-229.939;//calibrated conversion of digital voltage level to temperature 
}

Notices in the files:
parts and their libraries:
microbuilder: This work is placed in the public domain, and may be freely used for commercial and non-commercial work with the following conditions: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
